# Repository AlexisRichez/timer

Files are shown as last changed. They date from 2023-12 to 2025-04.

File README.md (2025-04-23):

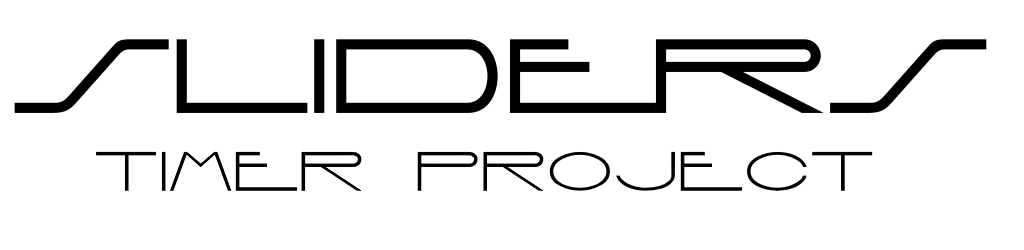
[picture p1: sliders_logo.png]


## Table of Contents
1. [Introduction](#introduction)
2. [Schematics](#schematics)
3. [PCB](#pcb)
4. [Power Supply](#power-supply)
5. [Hardware](#hardware)
6. [Sources](#sources)
7. [Remaining tasks](#remaining-tasks)

## Introduction
### About the story...
Sliders is a 1995 sci-fi television series :tv: that follows Quinn Mallory, a young genius who invents a device called the "Timer" that allows him and a small group of friends—Wade, Rembrandt, and Professor Arturo—to travel between parallel universes. Each universe presents a different version of Earth with unique cultures, histories, and technologies. The group "slides" from one world to the next, searching for their way back home while facing various challenges along the way.

The "Timer" is a handheld device that controls the sliding process, dictating how long the group must stay in each universe before they can slide again. It opens a wormhole :cyclone: at set intervals, and if the group misses their window, they are stranded in the current universe. The Timer becomes central to the story, especially when it malfunctions or is damaged, leading to unpredictable slides or dangerous situations.

### This is Open Source !
<b>Source Code:</b> You can download and modify the entire source code to suit your requirements. Whether you want to fix a bug, add new features, or create your own version, the choice is yours!

<b>3D Models:</b> All 3D models I use are accessible and can be adjusted. If you want to tweak the designs or use them for your own projects, you are free to do so.

<b>Vector Files:</b> Any vector graphic files I provide can also be edited. This includes things like logos, UI components, and other design assets that you can adapt for personal use.

> [!IMPORTANT]
> Feel free to fork this project for your own needs, or contribute directly by making a pull request :blush: :heart:

## Schematics
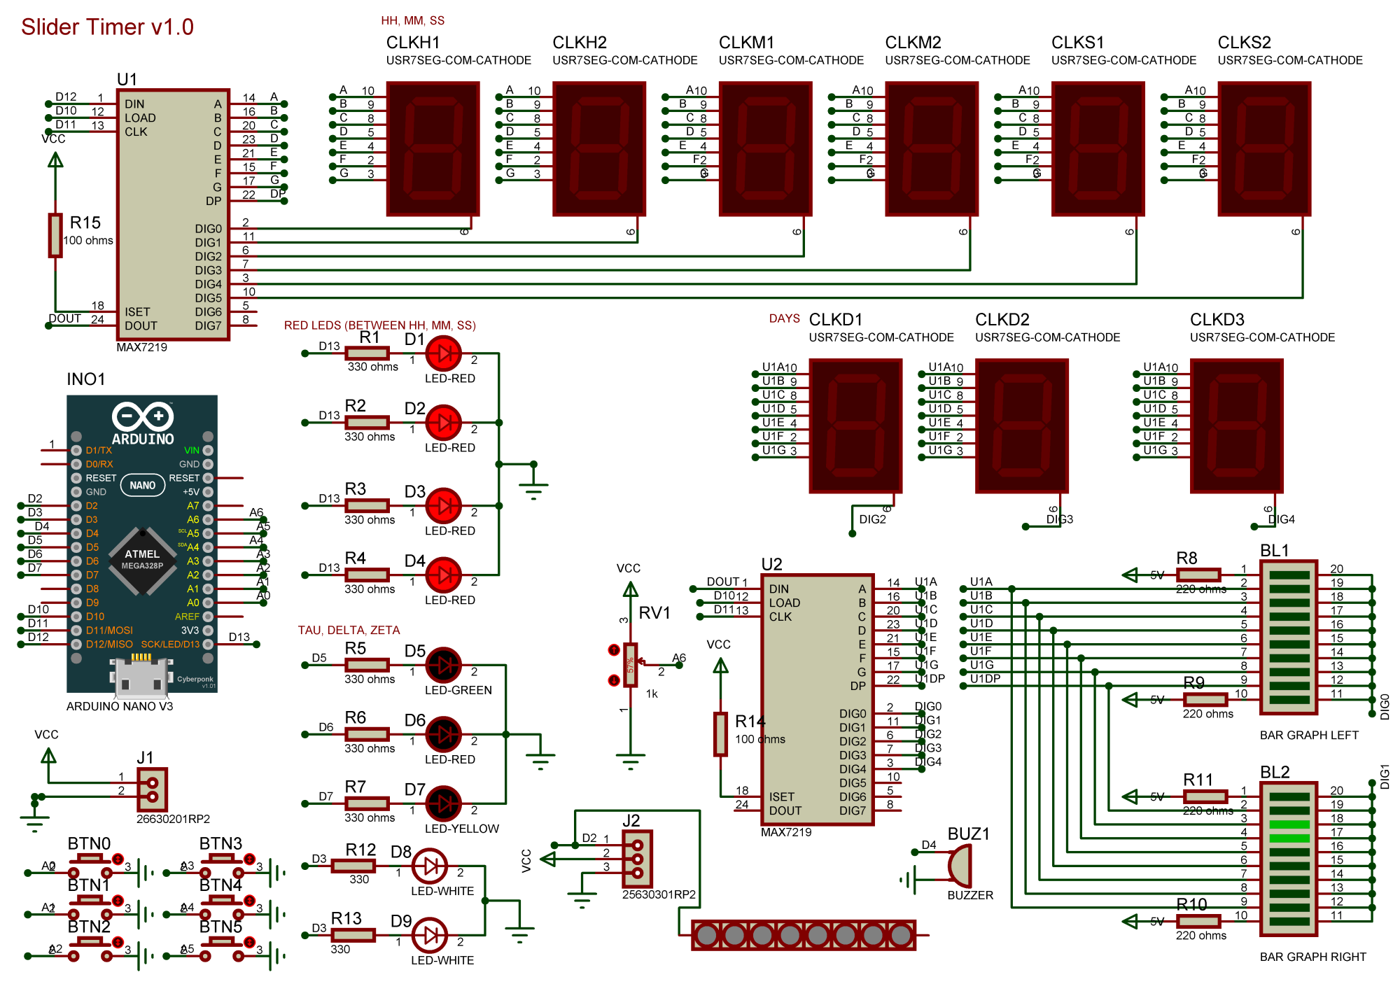
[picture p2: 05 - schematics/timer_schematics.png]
<br/>
## PCB
Size : 137mm x 50mm
## Power supply
### LiPo 3,7V 3000mAh 1S 1C
https://www.amazon.fr/dp/B08V11Z88Q
### Wemos D1 Battery Shield
The Wemos D1 Battery Shield is an expansion board designed for the Wemos D1 Mini series, allowing it to run on a lithium-ion (Li-Ion) or lithium-polymer (LiPo) battery. It features a TP4056 charging circuit for safe battery charging via micro-USB and includes a boost converter to provide a stable 5V output from the battery. Additionally, it has built-in overcharge and discharge protection to extend battery life and ensure safe operation. This shield is ideal for portable IoT projects, wireless sensor nodes, and other battery-powered applications.

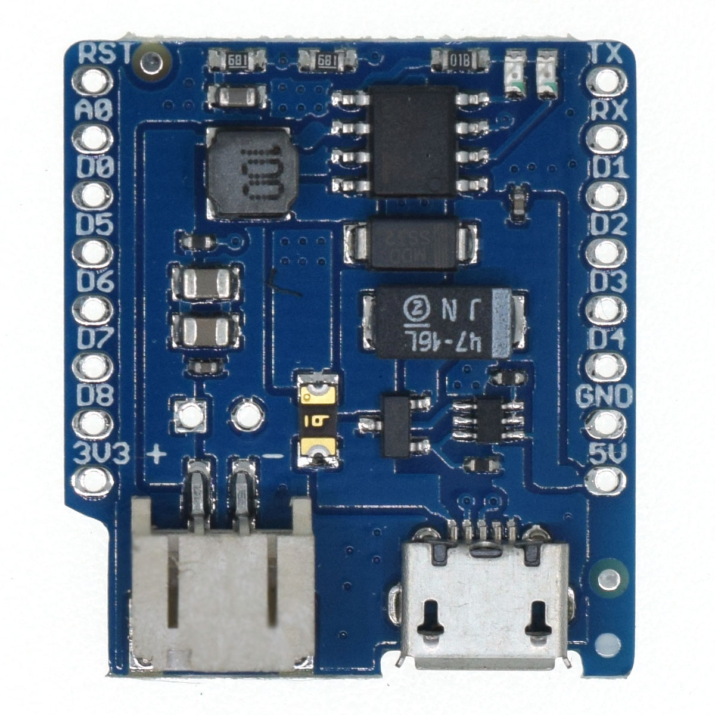
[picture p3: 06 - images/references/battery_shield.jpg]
<br/>

https://www.wemos.cc/en/latest/d1_mini_shield/battery.html
## Hardware
### Bill of materials
| Component | Link |
|---|---|
| 7 segment red LED digit - 0.36 inch cathode (HH:MM:SS) | https://fr.aliexpress.com/item/1005002680227414.html |
| 7 segment red LED digit - 0.3 inch cathode (DDD) | https://fr.aliexpress.com/item/32726538415.html |
| 10 green LEDs bargraph | https://fr.aliexpress.com/item/1005006697608767.html |
| Yellow, red, green LEDs (TAU, DELTA, ZETA) | https://fr.aliexpress.com/item/1005005678632501.html |
| Red LEDs (between HH:MM:SS) | https://fr.aliexpress.com/item/1005005678632501.html |
| Light LEDs (top laser) | https://fr.aliexpress.com/item/32468733055.html |
| Buzzer | https://fr.aliexpress.com/item/1005006209077202.html |
| Potentiometer 10k | https://fr.aliexpress.com/item/1005005671238738.html |
| Red acrylic sheets | [https://fr.aliexpress.com/item/4000283087852.html](https://fr.aliexpress.com/item/4000283087852.html) |
| Translucent acrylic sheets | [https://fr.aliexpress.com/item/4000283087852.html](https://fr.aliexpress.com/item/1005004925861639.html) |
| Arduino Nano V3 | [https://www.amazon.fr/dp/B0722YYBSS](https://www.amazon.fr/dp/B0722YYBSS) |

### Component Dimensions
> [!TIP]
> These are the dimensions used for the project. You should be able to use any component that adheres to these dimensions without needing to adapt anything on the PCB.

| Component | Length (mm) | Width (mm) | Height (mm) |
|---|---|---|---|
| 7 segment red LED digit - 0.36 inch cathode (HH:MM:SS) | 14.00 | 7.40 | 7.20 |
| 7 segment red LED digit - 0.3 inch cathode (DDD) | 12.70 | 7.60 | 7.00 |
| 10 green LEDs bargraph | 25.40 | 10.10 | 7.90 |
| Yellow, red, green LEDs (TAU, DELTA, ZETA) | 5.00 | 2.00 | 7.00 |
| Red LEDs (between HH:MM:SS) | 3.00 | 2.00 | 4.00 |
| Potentiometer 10k | - | - | - |

## Assembly & Finishing Tips
### Holes
The holes are designed for use with M2 or M3 inserts. Depending on the 3D printing technology used, the hole dimensions may need to be adjusted to ensure a precise fit:

- For filament prints :<br/>
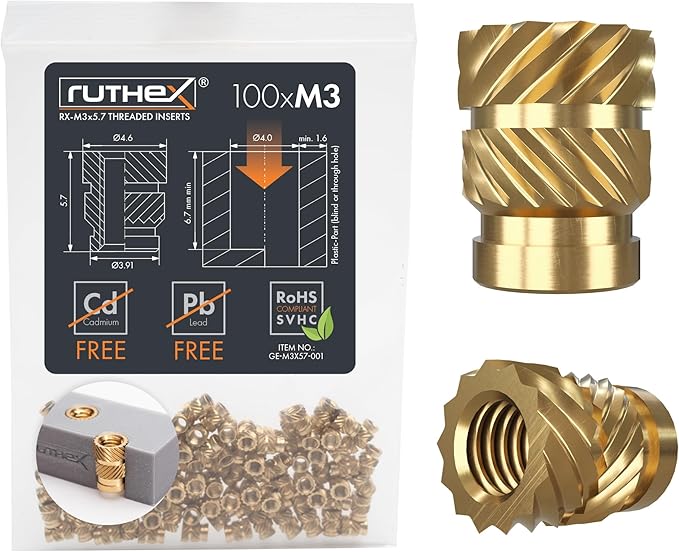
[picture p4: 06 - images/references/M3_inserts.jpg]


- For resin prints :<br/>
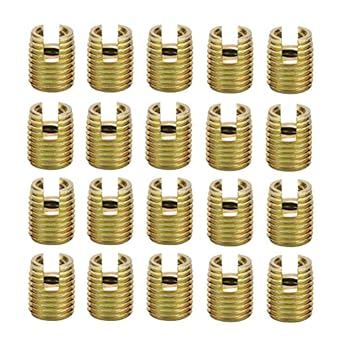
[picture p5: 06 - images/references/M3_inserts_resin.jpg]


### Buttons
For best results, print the buttons in white using a resin printer. After printing, spray them with black paint, then lightly sand the top surface — the text will become clearly visible. You can finish by applying a coat of varnish for protection and a polished look.

## 3D models
Timer 3D model preview : https://3dviewer.net/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<br/>
PCB 3D model preview : https://3dviewer.net/#model=https://raw.githubusercontent.com/AlexisRichez/timer/main/01%20-%20proteus/pcb.3DS

<div style="float:left">
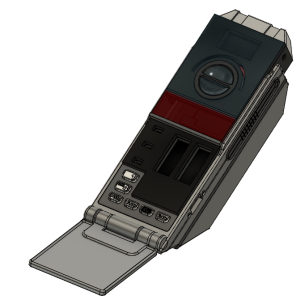
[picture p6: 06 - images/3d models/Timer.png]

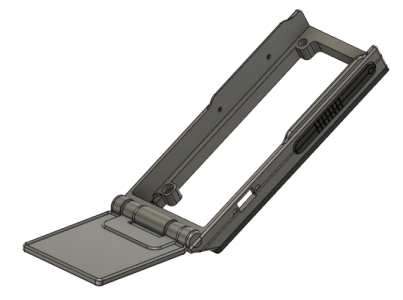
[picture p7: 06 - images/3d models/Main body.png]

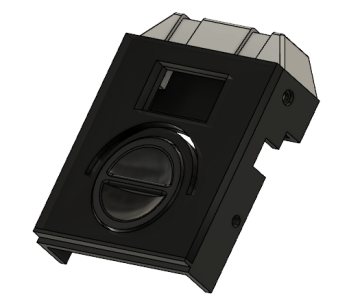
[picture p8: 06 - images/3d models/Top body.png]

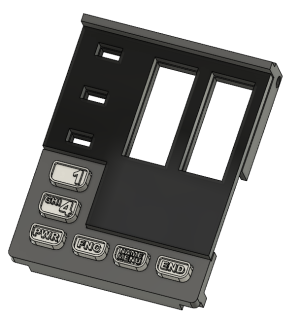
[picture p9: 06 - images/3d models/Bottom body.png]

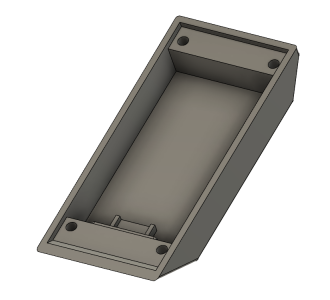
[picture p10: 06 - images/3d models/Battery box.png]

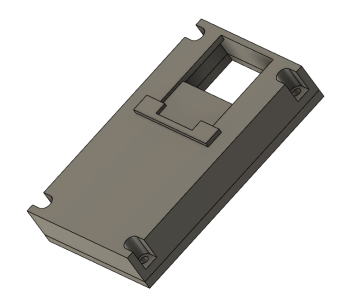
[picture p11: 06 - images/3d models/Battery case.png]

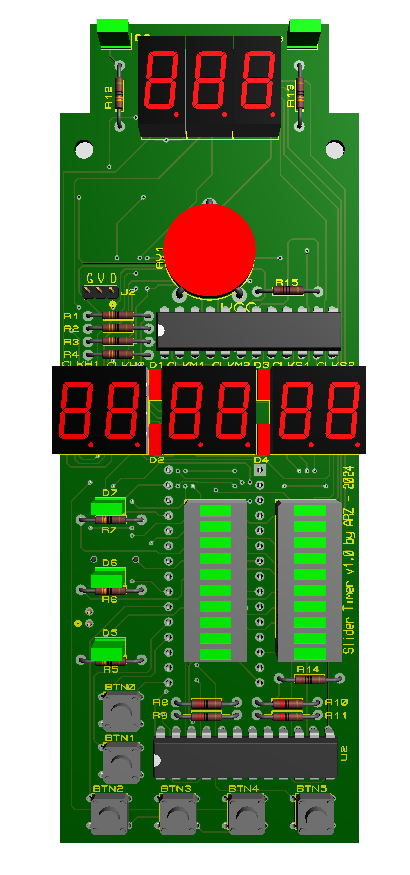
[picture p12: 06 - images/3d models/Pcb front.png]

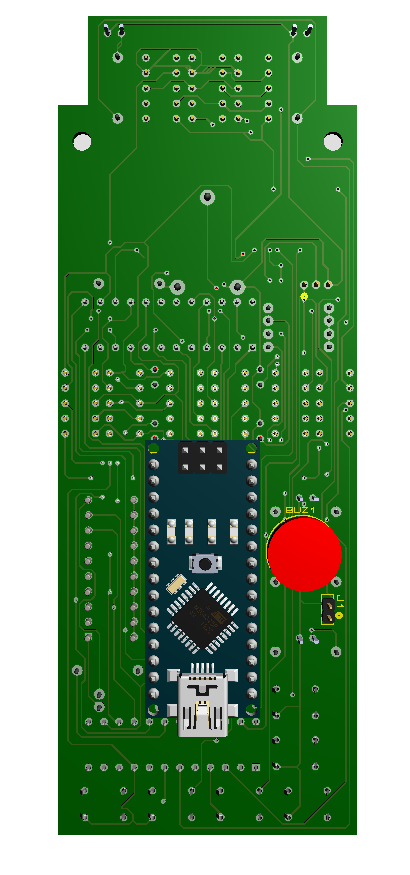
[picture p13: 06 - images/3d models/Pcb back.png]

</div>
<hr style="clear:both"/>

## Sources
+ [https://www.therpf.com/forums/threads/how-to-build-sliders-timer-electronics.104308/](https://www.therpf.com/forums/threads/how-to-build-sliders-timer-electronics.104308/)
+ https://github.com/kenny-caldieraro/Sliders-timer-replica

## Thingiverse
STL files are available on Thingiverse : https://www.thingiverse.com/thing:7009968

## Remaining tasks
:tada: Issues and improvments are available here : https://github.com/AlexisRichez/timer/issues<br/>

## Pictures :camera:
<div style="float:left">
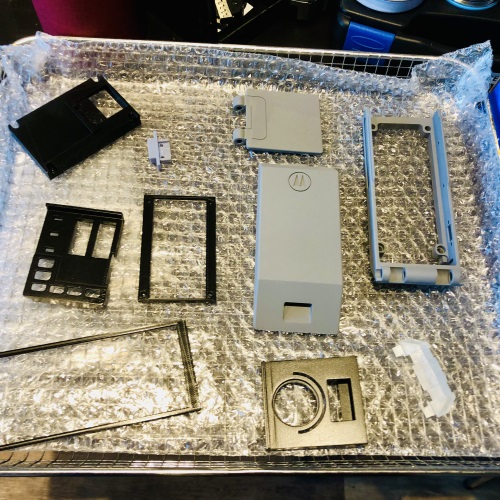
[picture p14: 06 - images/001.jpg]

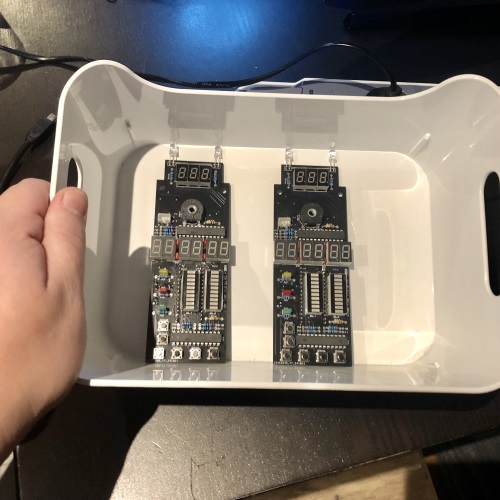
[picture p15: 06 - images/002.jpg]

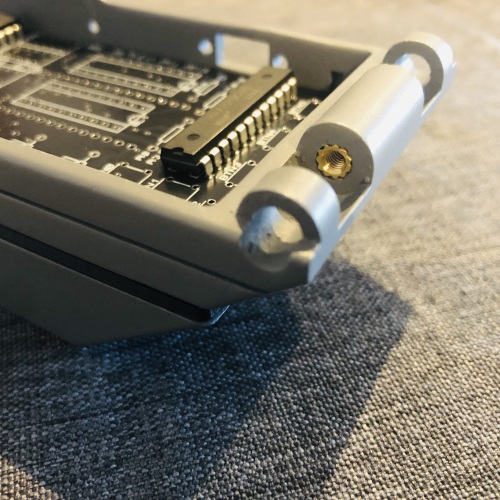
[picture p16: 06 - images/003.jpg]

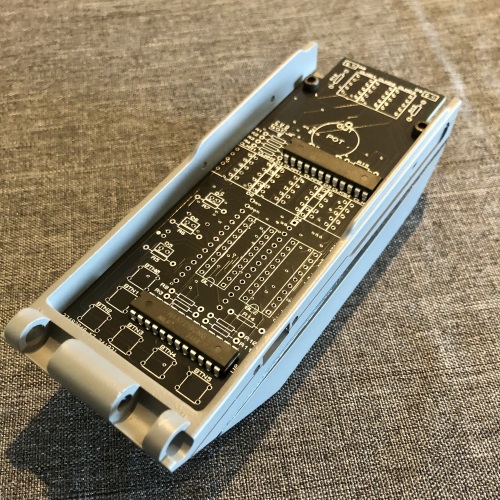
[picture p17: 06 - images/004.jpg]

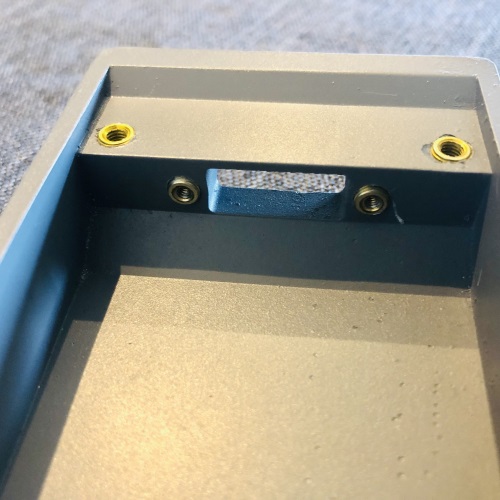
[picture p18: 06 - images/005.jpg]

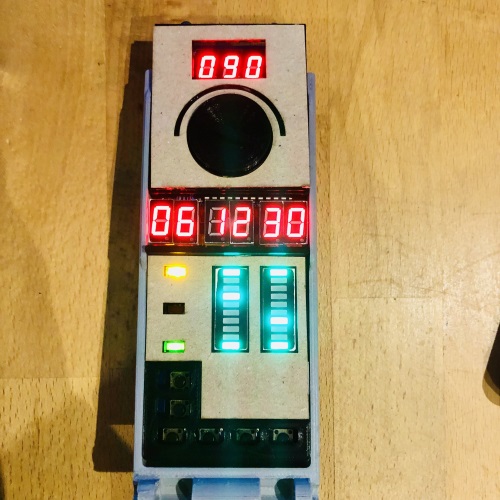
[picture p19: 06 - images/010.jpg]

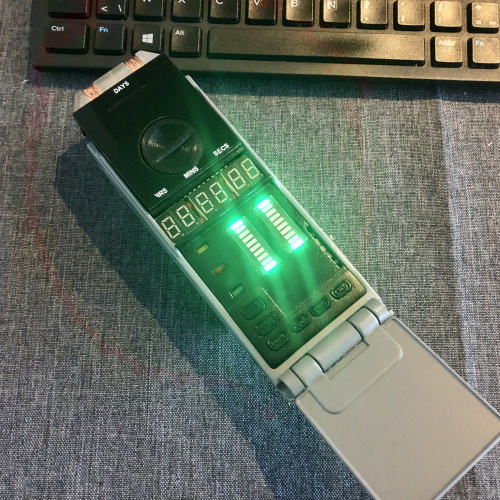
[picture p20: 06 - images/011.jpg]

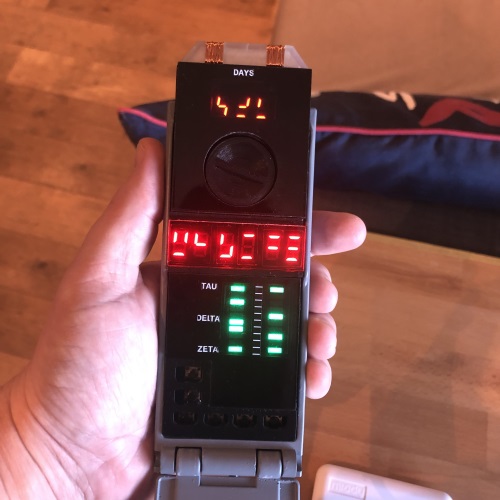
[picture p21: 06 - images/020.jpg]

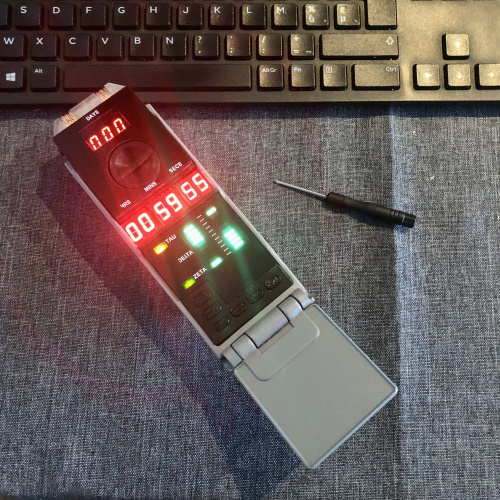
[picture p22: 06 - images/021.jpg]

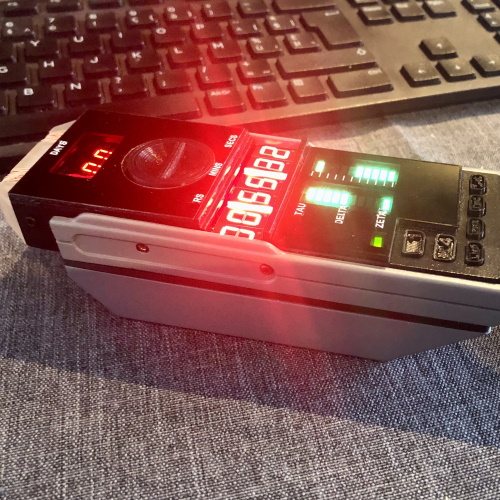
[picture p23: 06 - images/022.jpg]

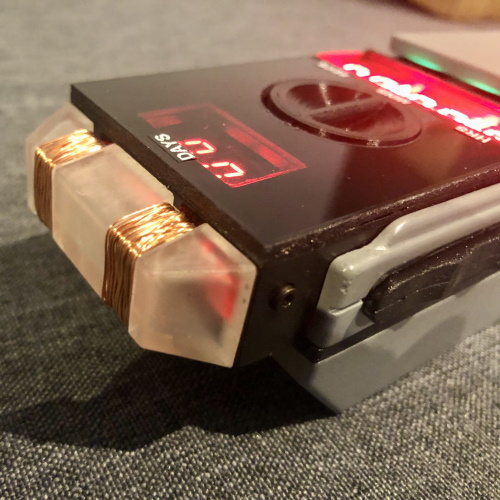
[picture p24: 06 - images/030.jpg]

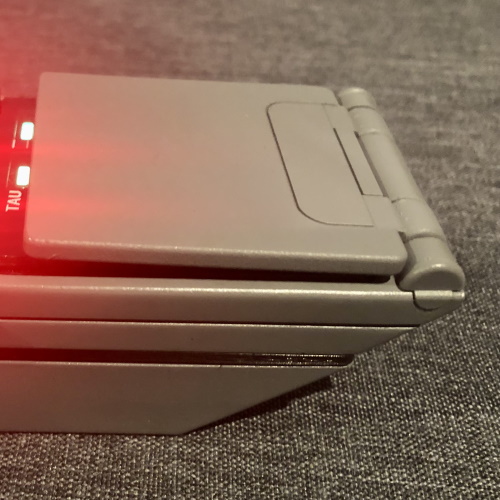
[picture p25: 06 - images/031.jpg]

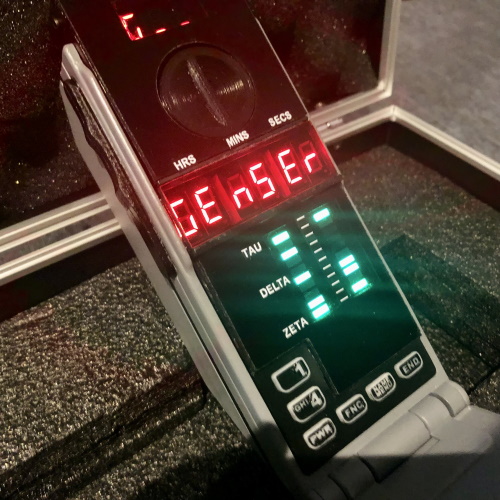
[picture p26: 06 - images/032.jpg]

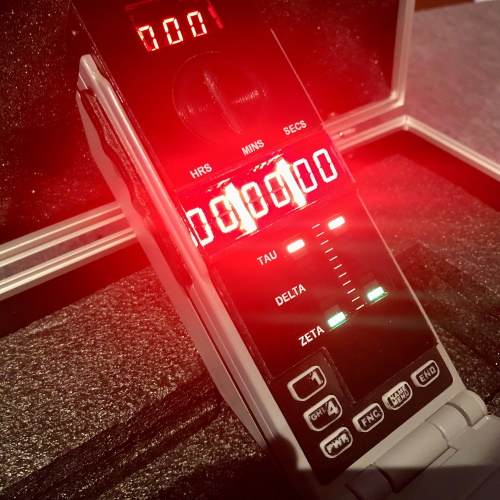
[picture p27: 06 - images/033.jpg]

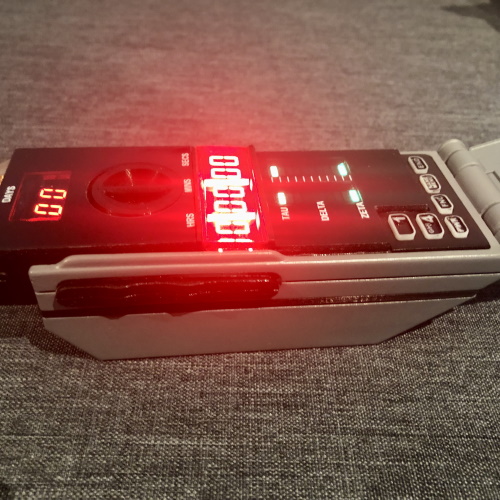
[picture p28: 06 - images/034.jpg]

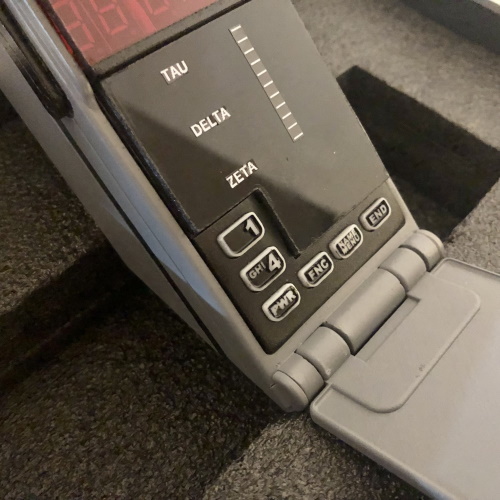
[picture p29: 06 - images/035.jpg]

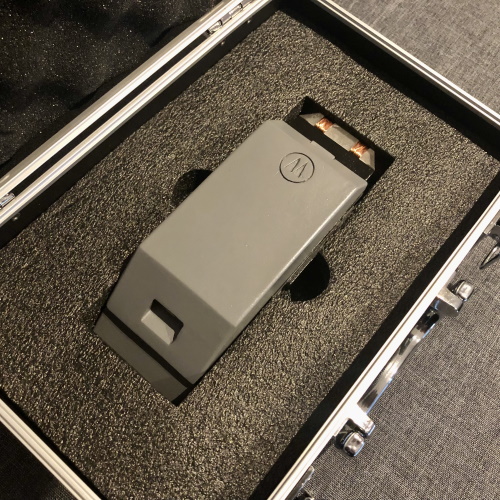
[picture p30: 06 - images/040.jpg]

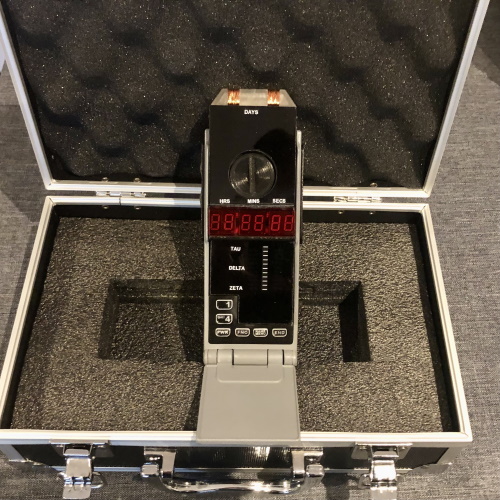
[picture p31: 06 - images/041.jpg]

</div>

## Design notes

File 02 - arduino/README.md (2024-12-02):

> [!TIP]
> You can download and modify the entire source code to suit your requirements. Whether you want to fix a bug, add new features, or create your own version, the choice is yours!

| Directory | Description |
| --- | --- |
| 01_test_components  | Can be used to simply test your PCB without any extra features  |
| 02_timer  | Timer source code :smirk:  |

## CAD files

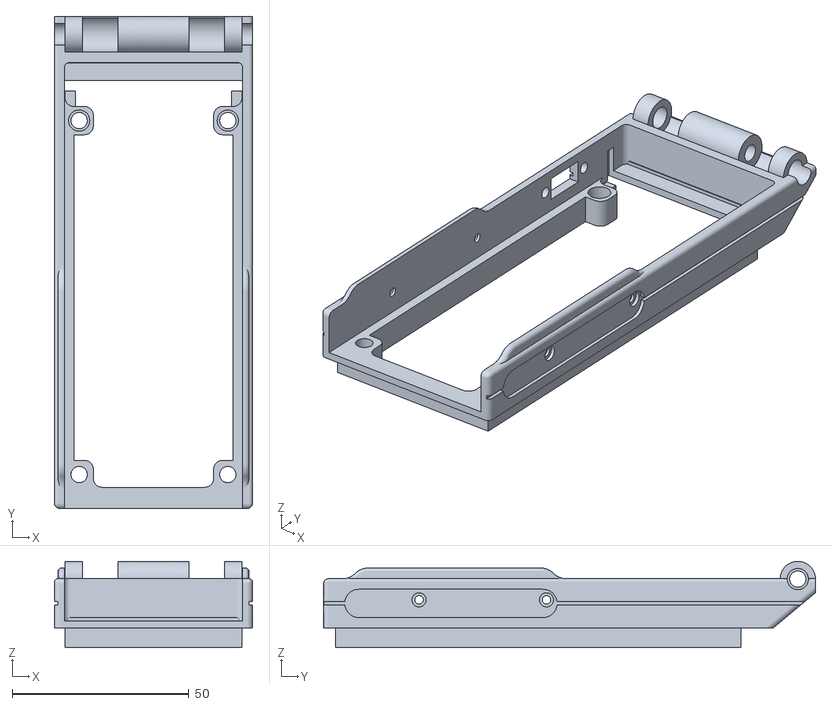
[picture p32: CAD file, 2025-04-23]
04 - stl/Main body.stl
56.0 x 139.0 x 24.4

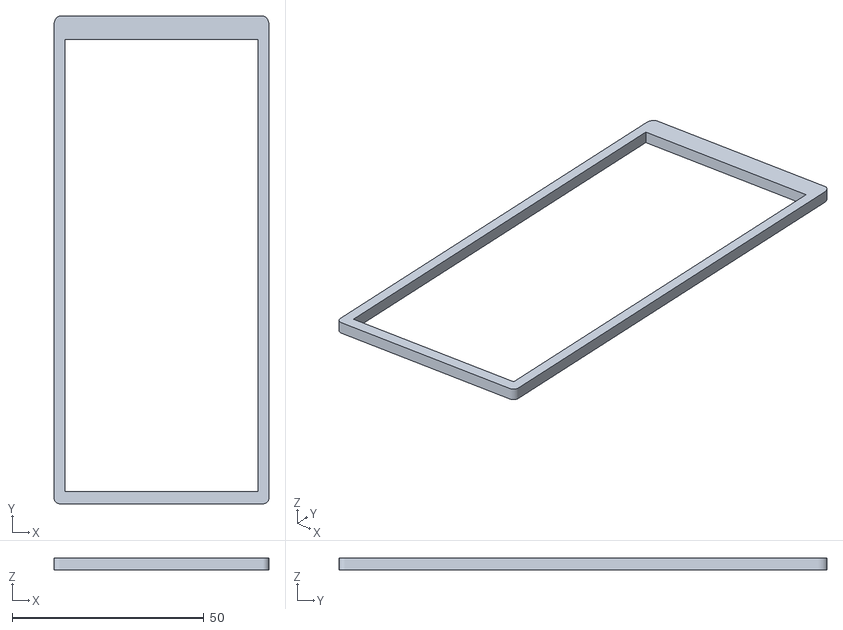
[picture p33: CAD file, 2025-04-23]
04 - stl/Main Body Frame.stl
56.0 x 127.0 x 3.00

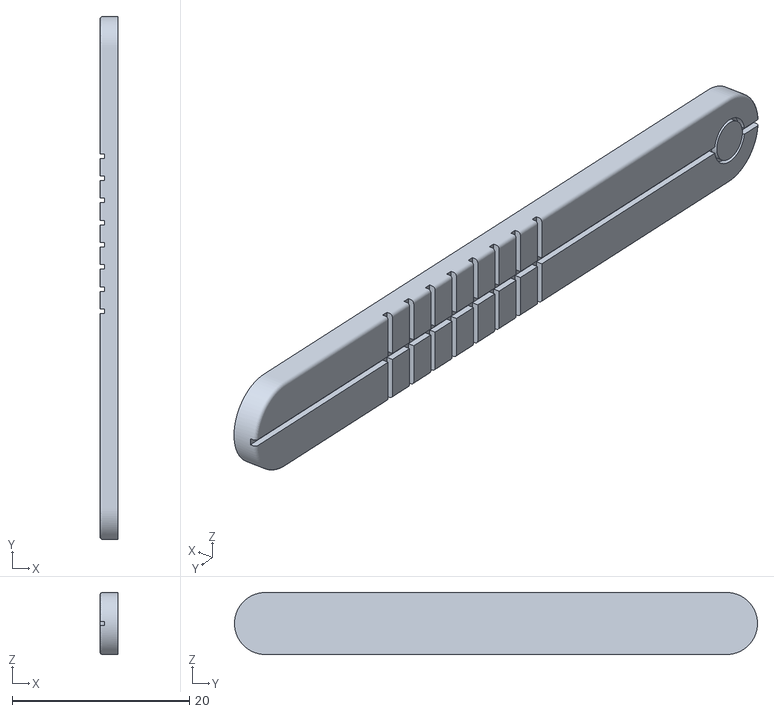
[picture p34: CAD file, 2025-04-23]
04 - stl/Main Body Right Side Panel.stl
2.00 x 59.0 x 7.00

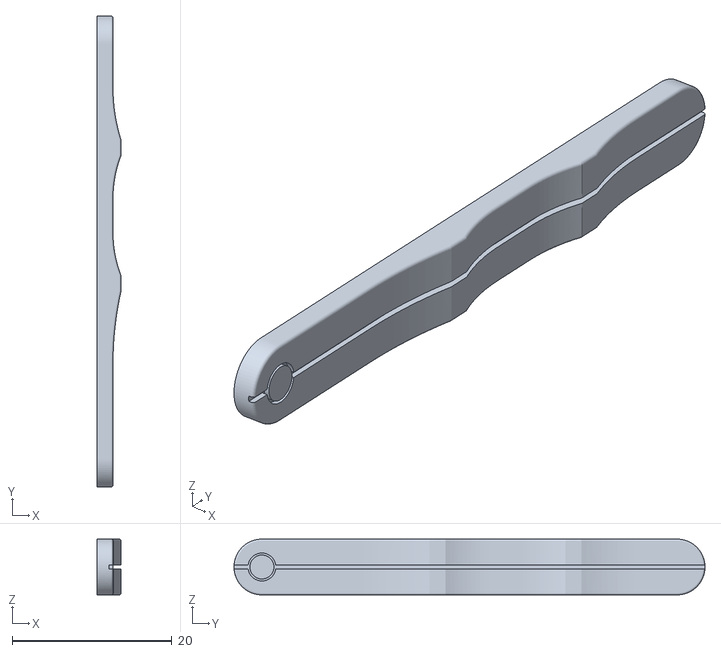
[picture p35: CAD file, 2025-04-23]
04 - stl/Main Body Left Side Panel.stl
3.00 x 59.0 x 7.00

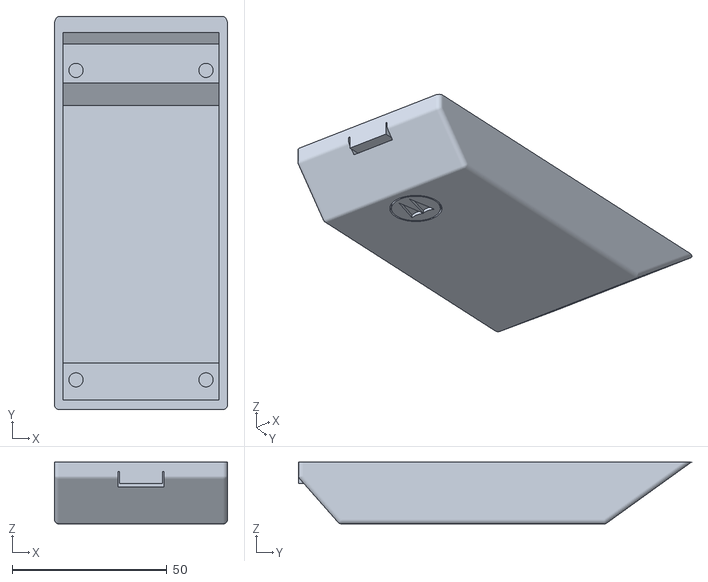
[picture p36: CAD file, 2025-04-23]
04 - stl/Battery Box.stl
56.0 x 127.0 x 20.0

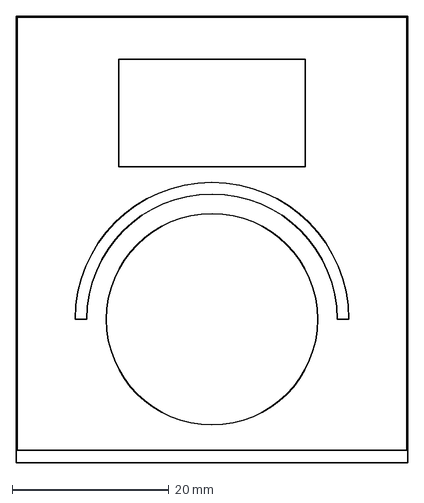
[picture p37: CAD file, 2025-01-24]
07 - laser cut/Laser cut - Top overlay.dxf
50.0 x 57.0 mm

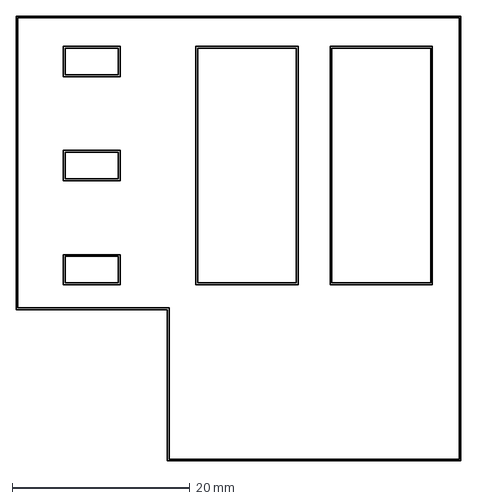
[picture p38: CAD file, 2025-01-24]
07 - laser cut/Laser cut - Bottom overlay.dxf
50.0 x 50.0 mm

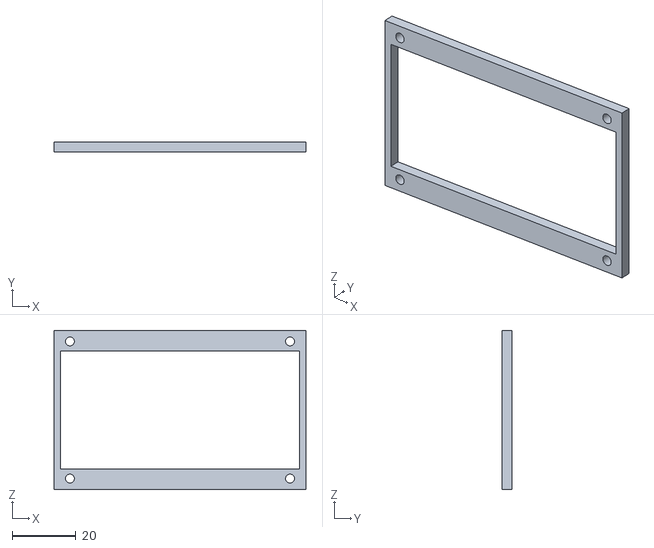
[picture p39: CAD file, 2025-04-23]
04 - stl/Battery Box Insert Support.stl
79.0 x 3.00 x 50.0

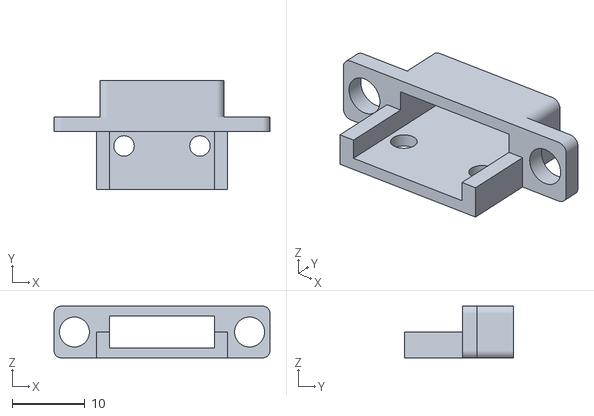
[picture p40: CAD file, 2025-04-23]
04 - stl/Battery Box Usb Adapter.stl
29.6 x 15.0 x 7.10

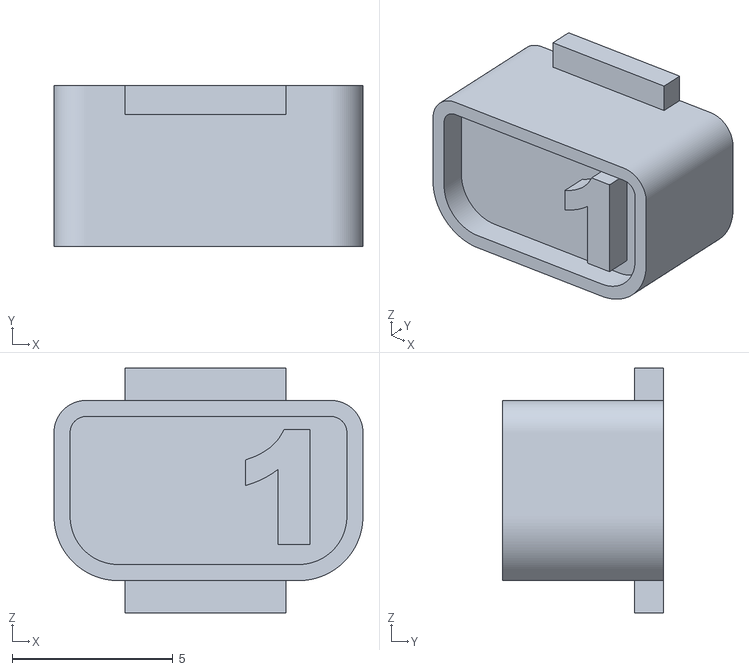
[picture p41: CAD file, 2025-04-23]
04 - stl/Button 1.stl
9.60 x 5.00 x 7.60

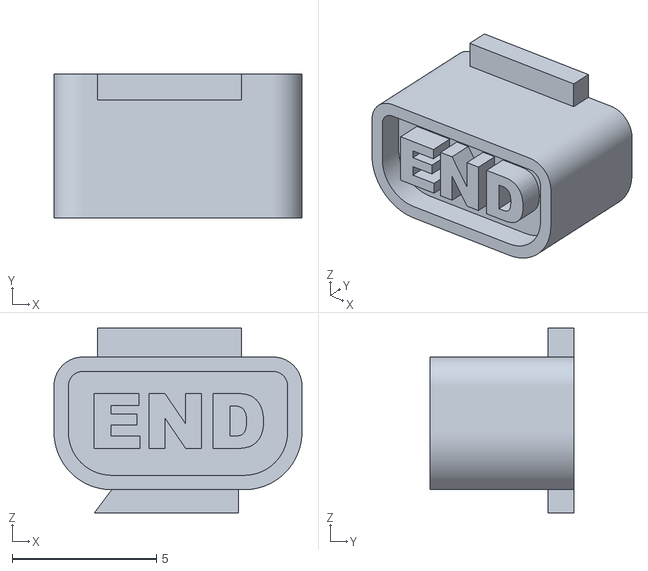
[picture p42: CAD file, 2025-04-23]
04 - stl/Button END.stl
8.60 x 5.00 x 6.40

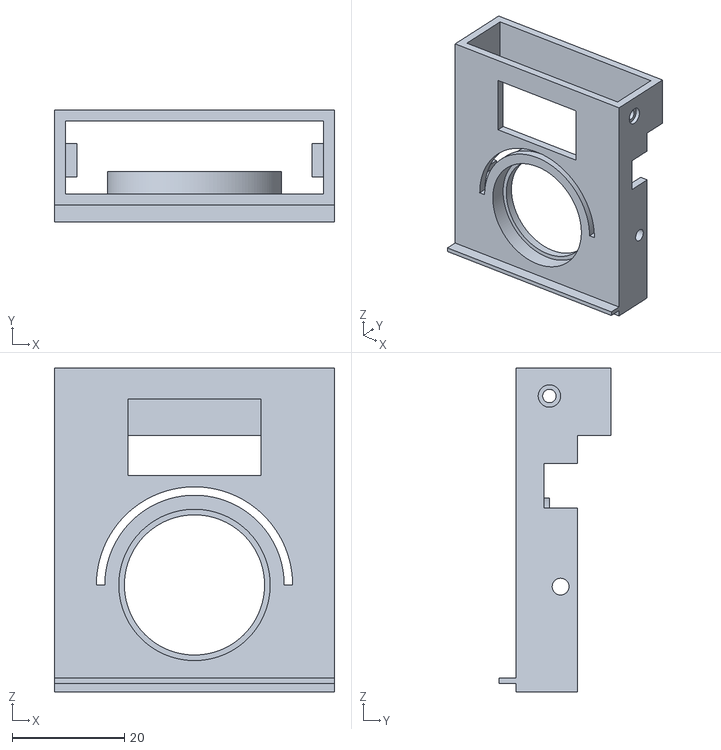
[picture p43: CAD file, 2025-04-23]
04 - stl/Top Plate.stl
50.0 x 20.0 x 57.8

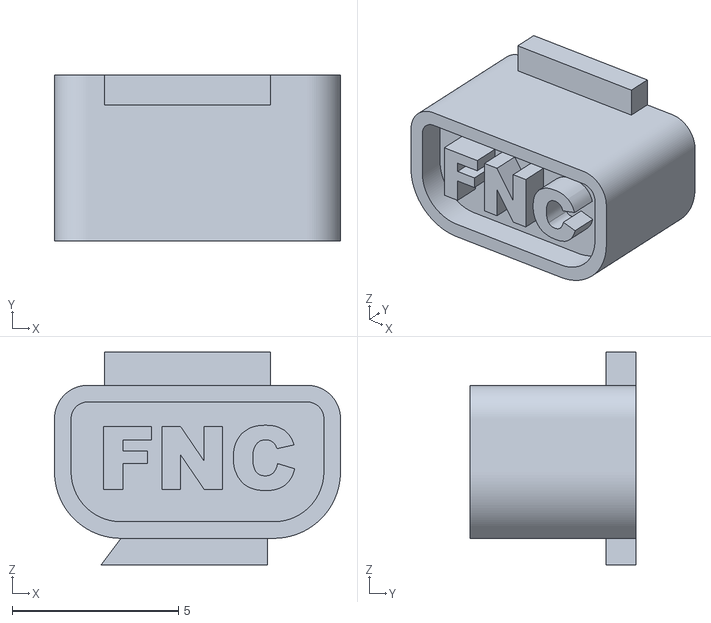
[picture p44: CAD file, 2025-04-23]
04 - stl/Button FCN.stl
8.60 x 5.00 x 6.40

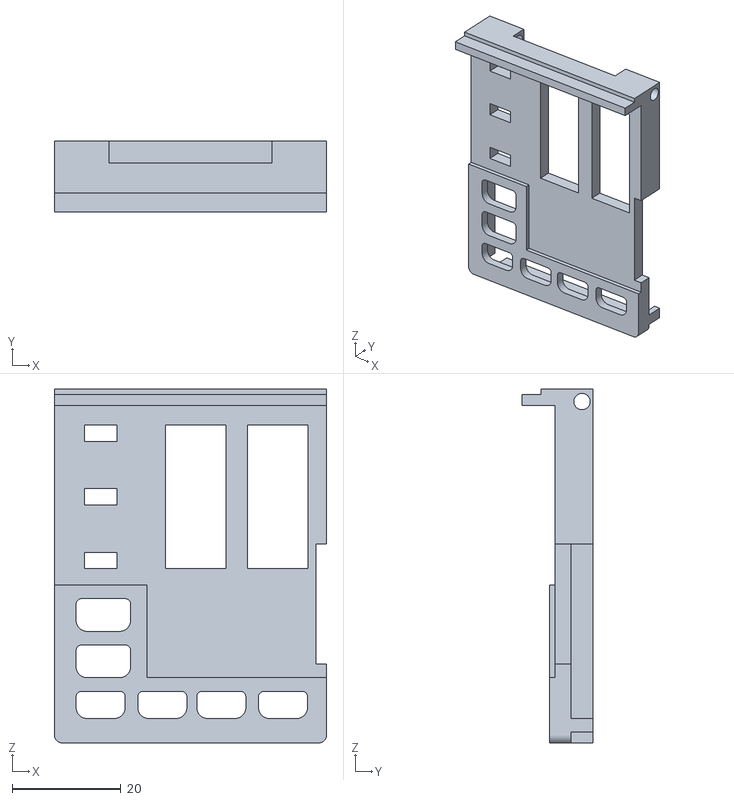
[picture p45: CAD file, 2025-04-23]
04 - stl/Bottom Plate.stl
50.0 x 13.0 x 65.0

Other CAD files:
04 - stl/Bottom Plate Flip Cover.stl
04 - stl/Bouton PWR.stl
04 - stl/Button NAME.stl
04 - stl/Top Plate Rounded button.stl
03 - fusion360/v2 - Timer - Assembly.f3z
03 - fusion360/v2 - Timer - Battery box.f3d
03 - fusion360/v2 - Timer - Bottom overlay.f3d
03 - fusion360/v2 - Timer - Led ring insert.f3d
03 - fusion360/v2 - Timer - Main body.f3d
03 - fusion360/v2 - Timer - PCB.f3d
03 - fusion360/v2 - Timer - Top overlay.f3d
04 - stl/Battery Box Insert.stl
04 - stl/Button 4.stl
04 - stl/Side Screw Hide Left.stl
04 - stl/Side Screw Hide Right.stl
04 - stl/Top Plate Laser.stl

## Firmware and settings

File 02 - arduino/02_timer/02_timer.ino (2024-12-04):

#include "LedControl.h"
#include "OneButton.h"
#include "Adafruit_NeoPixel.h"

//Source for specs : https://www.therpf.com/forums/threads/how-to-build-sliders-timer-electronics.104308/

// MAX7219 configuration
#define PIN_MAX72_DATA_IN 12
#define PIN_MAX72_CLK 11
#define PIN_MAX72_LOAD 10
#define MAX72_NB_DEVICES 2
LedControl lc = LedControl(PIN_MAX72_DATA_IN, PIN_MAX72_CLK, PIN_MAX72_LOAD, MAX72_NB_DEVICES);

// Global led configuration
#define DEFAULT_INTENSITY_LED 10

//Slide lights (white leds on top)
#define PIN_WHITE_COLONS_LED 3

// Power led ring
#define LEDRING_PIN 2
#define LEDRING_NUMPIXELS 8
Adafruit_NeoPixel pixels(LEDRING_NUMPIXELS, LEDRING_PIN, NEO_GRB + NEO_KHZ800);
int Pot;

//Buzzer
#define PIN_BUZZER 4

//Red led columns (Between HH, MM, SS)
#define PIN_RED_COLONS_LED 13
long blinkRedColumnsIntervalDefault = 500;
long blinkRedColumnsInterval = blinkRedColumnsIntervalDefault;
long previousBlinkRedColumnsMillis = 0;
bool redColumnsStatus = false;

// TAU, DELTA, ZETA
#define PIN_YELLOW_LED 7
#define PIN_RED_LED 6
#define PIN_GREEN_LED 5
bool tauStatus = false;
bool deltaStatus = false;
bool zetaStatus = false;
unsigned long previousBlinkTauMillis = 0;
unsigned long previousBlinkDeltaMillis = 0;
unsigned long previousBlinkZetaMillis = 0;

//Buttons
const unsigned long debounceDelay = 50; // Debounce delay in milliseconds
unsigned long lastDebounceTimes[6] = {0}; // Last debounce times for each button
static bool lastButtonStates[6] = {HIGH, HIGH, HIGH, HIGH, HIGH, HIGH}; // Track previous button states
static bool actionButtonExecuted[6] = {false}; // Track whether the action has been executed

#define BTN_1 A0
#define BTN_2 A1
#define BTN_3 A2
#define BTN_4 A3
#define BTN_5 A4
#define BTN_6 A5

//Edit mode
long previousBlinkEditModeMillis = 0;
long previousBlinkEditModeInterval = 250;
bool editModeBlinkStatus = false;

//Bargraph
byte bargraph_patterns[] = {
  B00000000,
  B10000000,
  B10000001,
  B10000011,
  B10000111,
  B10001111,
  B10011111,
  B10111111,
  B11111111,
  B10111111,
  B10011111,B10001111,B10000111,B10000011,B10000001,B10000000
  };
#define BARGRAPH_INTERVAL 100 // Bar graph interval in milliseconds
#define BARGRAPH_NUM_PATTERNS (sizeof(bargraph_patterns) / sizeof(bargraph_patterns[0]))
byte bargraphPatternIndex = 0; // Index to track which pattern to show
unsigned long previousBarGraphMillis = 0;

//Timer management
unsigned long previousTimerMillis = 0;
unsigned long totalsectime = 0;
bool firstLoop = true;
bool nextLoop = false;
bool randomMode = false;
bool editMode = true;
long editModeCurrent = 0;
long editModeSeconds = 0;
long editModeMinutes = 0;
long editModeHours = 0;
long editModeDays = 0;
bool powerOn = false;
bool isTimerOn = false;
bool countdownEndTriggered = false;
bool isTimerSleepMode = false;

//Options
const bool buzzerActivated = true;

void setup()
{
  Serial.println("Sliders Timer System by ARZ");
  Serial.println("===========================================");
  Serial.println("Made with love in FRANCE");
  
  Serial.begin(115200);

  randomSeed(analogRead(0)); // Seed the random number generator with an analog reading
  
  //Two MAX7219 initialisation
  int devices = lc.getDeviceCount();
  for (int address = 0; address < devices; address++)
  {
    lc.shutdown(address, false);
    lc.clearDisplay(address);
    lc.setIntensity(address, DEFAULT_INTENSITY_LED);
    lc.setScanLimit(address, 8);
  }

  //Buzzer
  pinMode(PIN_BUZZER, OUTPUT);
  //Red led two columns
  pinMode(PIN_RED_COLONS_LED, OUTPUT);
  //Slide lights on top
  pinMode(PIN_WHITE_COLONS_LED, OUTPUT);

  //TAU, DELTA, ZETA
  pinMode(PIN_GREEN_LED, OUTPUT);
  pinMode(PIN_RED_LED, OUTPUT);
  pinMode(PIN_YELLOW_LED, OUTPUT);

  //Buttons
  pinMode(BTN_1, INPUT_PULLUP);
  pinMode(BTN_2, INPUT_PULLUP);
  pinMode(BTN_3, INPUT_PULLUP);
  pinMode(BTN_4, INPUT_PULLUP);
  pinMode(BTN_5, INPUT_PULLUP);
  pinMode(BTN_6, INPUT_PULLUP);

  //Calculate next random countdown only if we are in random mode
  if(randomMode)
  {
    setNextRandCountdown();
  }
}

//Deactivate slide mode : reset everything specific to slide mode (X min before countdown end)
void deactivateSlideMode()
{
  deactivateSlideLights();
}

//Activate slide mode
void activateSlideMode()
{
  activateSlideLights();
}

//Define next random countdown
void setNextRandCountdown()
{
  Serial.println("Set next random countdown...");
  //totalsectime = random(16756131);
  totalsectime = random(600, 604800); //Random between 10 minutes and 7 days
  Serial.println("Total time in seconds : " + totalsectime);
  countdownEndTriggered = false;
}

//Deactivate slide lights
void deactivateSlideLights()
{
    digitalWrite(PIN_WHITE_COLONS_LED, LOW);
}

//Acticate slide lights
void activateSlideLights()
{
    digitalWrite(PIN_WHITE_COLONS_LED, HIGH);
}

//Activate red led columns
void activateRedColumnsLeds()
{
  digitalWrite(PIN_RED_COLONS_LED, HIGH);
}

//Blink  red leds columns
void blinkRedColumnsLeds()
{
  unsigned long currentMillis = millis();
  if (currentMillis - previousBlinkRedColumnsMillis >= blinkRedColumnsInterval)
  {
    previousBlinkRedColumnsMillis = currentMillis;
    blinkRedColumnsInterval = blinkRedColumnsIntervalDefault;
    
    //When 30 seconds or less are remaining, red leds and buzzer speeds up
    if(totalsectime<=30)
    {
      blinkRedColumnsInterval = 150;
    }

    // Toggle the LED status
    redColumnsStatus = !redColumnsStatus;
    
    //Blink red colons
    if(redColumnsStatus && buzzerActivated && totalsectime<=60)
    {
      tone(PIN_BUZZER, 5500, 100);
    }
    
    // Update the LED output based on the status
    digitalWrite(PIN_RED_COLONS_LED, redColumnsStatus ? HIGH : LOW);
  }
}

//Blink TAU
void blinkTAU()
{
  unsigned long currentMillis = millis();
  if (currentMillis - previousBlinkTauMillis >= 250)
  {
    previousBlinkTauMillis = currentMillis;
    if((totalsectime >= 15 && totalsectime <= 35)) {
      digitalWrite(PIN_YELLOW_LED, HIGH);
    } else {
      tauStatus = !tauStatus;
      digitalWrite(PIN_YELLOW_LED, tauStatus ? HIGH : LOW);
    }
  }
}

//Blink DELTA
void blinkDELTA()
{
  unsigned long currentMillis = millis();
  if (currentMillis - previousBlinkDeltaMillis >= 600)
  {
    previousBlinkDeltaMillis = currentMillis;
    if((totalsectime >= 0 && totalsectime <= 15)) {
      digitalWrite(PIN_RED_LED, HIGH);
    } else {
      deltaStatus = !deltaStatus;
      digitalWrite(PIN_RED_LED, deltaStatus ? HIGH : LOW);
    }
  }  
}

//Blink ZETA
void blinkZETA()
{
  unsigned long currentMillis = millis();
  if (currentMillis - previousBlinkZetaMillis >= 200)
  {
    previousBlinkZetaMillis = currentMillis;
    if((totalsectime >= 35 && totalsectime <= 59)) {
      digitalWrite(PIN_GREEN_LED, HIGH);
    } else {  
      zetaStatus = !zetaStatus;
      digitalWrite(PIN_GREEN_LED, zetaStatus ? HIGH : LOW);
    }
  }
}

//Blink TAU, DELTA, ZETA leds
void blinkTDZ()
{
  if(isTimerSleepMode)
  {
    digitalWrite(PIN_YELLOW_LED, LOW);
    digitalWrite(PIN_RED_LED, LOW);
    digitalWrite(PIN_GREEN_LED, LOW);
    return;
  }
  blinkTAU();
  blinkDELTA();
  blinkZETA();
}

//Blink modification when in edit mode
void blinkEditMode()
{
  unsigned long currentMillis = millis();
  if (currentMillis - previousBlinkEditModeMillis >= previousBlinkEditModeInterval)
  {
    previousBlinkEditModeMillis = currentMillis;

    if(isTimerSleepMode)
    {
      return;
    }
    
    if (editMode) {
      if (editModeCurrent == 4)
      {
        int days = totalsectime / 86400;
        if (editModeBlinkStatus)
        {
          lc.setRow(1, 2, B00000000); // Turn off the display
          lc.setRow(1, 3, B00000000); // Turn off the display
          lc.setRow(1, 4, B00000000); // Turn off the display
        }
        else
        {
          lc.setDigit(1, 2, days / 100, false);
          lc.setDigit(1, 3, (days / 10) % 10, false);
          lc.setDigit(1, 4, days % 10, false); 
        }
      }
      if (editModeCurrent == 3)
      {
        int hours = (totalsectime % 86400) / 3600;
        if (editModeBlinkStatus)
        {
          lc.setRow(0, 0, B00000000);
          lc.setRow(0, 1, B00000000);
        }
        else
        {
          lc.setDigit(0, 0, hours / 10, false);
          lc.setDigit(0, 1, hours % 10, false);   
        }
      }
      if (editModeCurrent == 2)
      {
        int minutes = (totalsectime % 3600) / 60;
        if (editModeBlinkStatus)
        {
          lc.setRow(0, 2, B00000000);
          lc.setRow(0, 3, B00000000);
        }
        else
        {
          lc.setDigit(0, 2, minutes / 10, false);
          lc.setDigit(0, 3, minutes % 10, false);    
        }
      }
      if (editModeCurrent == 1)
      {
        int seconds = totalsectime % 60;
        if (editModeBlinkStatus)
        {
          lc.setRow(0, 4, B00000000);
          lc.setRow(0, 5, B00000000);
        }
        else
        {
          lc.setDigit(0, 4, seconds / 10, false);
          lc.setDigit(0, 5, seconds % 10, false);     
        }
      }
      // Toggle the blinking status
      editModeBlinkStatus = !editModeBlinkStatus;
    }
  }
}

//Refresh timer
void refreshTimer()
{
    //Serial.println("Refresh timer...");
    int days = totalsectime / 86400;
    int hours = (totalsectime % 86400) / 3600;// Calculate hours from the remaining seconds after days
    int minutes = (totalsectime % 3600) / 60; // Calculate minutes from the remaining seconds after hours
    int seconds = totalsectime % 60; // Calculate seconds from the remaining seconds

    if(isTimerSleepMode)
    {
      lc.setRow(1, 2, B00000000);
      lc.setRow(1, 3, B00000000);
      lc.setRow(1, 4, B00000000);
      lc.setRow(0, 0, B00000000);
      lc.setRow(0, 1, B00000000);          
      lc.setRow(0, 2, B00000000);
      lc.setRow(0, 3, B00000000);
      lc.setRow(0, 4, B00000000);
      lc.setRow(0, 5, B00000000);
      return;
    }
  
    days = min(days, 999);
  
    // Update DDD display
    if(editMode && editModeCurrent == 4)
    {
      Serial.println("Days are edited");
    } else {
      lc.setDigit(1, 2, days / 100, false);
      lc.setDigit(1, 3, (days / 10) % 10, false);
      lc.setDigit(1, 4, days % 10, false);   
    }
    // Update the HHMMSS display
    if(editMode && editModeCurrent == 3)
    {
      Serial.println("Hours are edited");
    } else {
     lc.setDigit(0, 0, hours / 10, false); // Display tens digit of hours
     lc.setDigit(0, 1, hours % 10, false); // Display ones digit of hours     
    }
    if(editMode && editModeCurrent == 2)
    {
      Serial.println("Minutes are edited");
    } else {
      lc.setDigit(0, 2, minutes / 10, false); // Display tens digit of minutes
      lc.setDigit(0, 3, minutes % 10, false); // Display ones digit of minutes      
    }
    if(editMode && editModeCurrent == 1)
    {
      Serial.println("Seconds are edited");
    } else {
      lc.setDigit(0, 4, seconds / 10, false); // Display tens digit of seconds
      lc.setDigit(0, 5, seconds % 10, false); // Display ones digit of seconds    
    }
}

//Timer management
void timer(bool editMode = false)
{
  unsigned long currentMillis = millis();
  // Update the timer every second
  if (currentMillis - previousTimerMillis >= 1000)
  {
    previousTimerMillis = currentMillis;
    if(!editMode)
    {
      if (totalsectime > 0) {
        totalsectime--; // Decrease the timer value by 1 second if it's greater than 0
        isTimerOn = true;
      }
      else {
        isTimerOn = false;
      }  
    }
  }

  refreshTimer();

  if(editMode)
  {
    return;
  }
  
  if(totalsectime <= 0)
  {
    if(!countdownEndTriggered)
    {
      slideOpenVortex();
      genserOne();
      displayWrap();      
      countdownEndTriggered = true;
    }
    //Calculate next random countdown only if we are in random mode
    if(randomMode)
    {
      setNextRandCountdown();
    }
  }
}

//Bargraph management
void bargraph()
{
  unsigned long currentMillis = millis();

  if (currentMillis - previousBarGraphMillis >= BARGRAPH_INTERVAL)
  {
    previousBarGraphMillis = currentMillis;

    // Display the current pattern from the array
    byte pattern = bargraph_patterns[bargraphPatternIndex];
    if(isTimerSleepMode)
    {
      lc.setRow(1, 0, B00000000);
      lc.setRow(1, 1, B00000000);
    } else {
      lc.setRow(1, 0, pattern);
      lc.setRow(1, 1, pattern);
    }
    // Update the patternIndex to cycle through the patterns
    bargraphPatternIndex++;
    if (bargraphPatternIndex >= BARGRAPH_NUM_PATTERNS) {
      bargraphPatternIndex = 0; // Reset to the first pattern when the last one is reached
    }
  }
}

//Buzzer startup management
void buzzerStartup() {
  Serial.println("Buzzer startup sequence...");
  tone(PIN_BUZZER, 5500, 150);
  delay(200);
  tone(PIN_BUZZER, 5500, 150);
  delay(200);
  tone(PIN_BUZZER, 5500, 10);
  delay(10);
  tone(PIN_BUZZER, 5500, 10);
  delay(10);
  tone(PIN_BUZZER, 5500, 10);
  delay(10);
  tone(PIN_BUZZER, 5500, 10);
  delay(10);
  tone(PIN_BUZZER, 5500, 10);
  delay(10);
  tone(PIN_BUZZER, 5500, 10);
  delay(10);
  tone(PIN_BUZZER, 5500, 10);
  delay(10);
  tone(PIN_BUZZER, 5500, 10);
  delay(10);
  tone(PIN_BUZZER, 5500, 10);
  delay(10);
  tone(PIN_BUZZER, 5500, 10);
  delay(10);
  tone(PIN_BUZZER, 5500, 10);
  delay(10);
  tone(PIN_BUZZER, 5500, 10);
  delay(10);
  tone(PIN_BUZZER, 5500, 10);
  delay(10);
  tone(PIN_BUZZER, 5500, 10);
  delay(10);
  tone(PIN_BUZZER, 5500, 10);
  delay(10);
  tone(PIN_BUZZER, 3500, 100);
  delay(100);
  tone(PIN_BUZZER, 3500, 500);
  delay(250);
  tone(PIN_BUZZER, 2500, 500);
  delay(250);
  tone(PIN_BUZZER, 1500, 500);
  delay(250);
  noTone(PIN_BUZZER);
  delay(250);
}
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
void loop()
{
  //Blink when in edit mode
  blinkEditMode();
  
  //Buttons clicks
  clickButton(BTN_1,clickBtn1Action);
  clickButton(BTN_2,clickBtn4Action);
  clickButton(BTN_3,clickBtnPowerAction);
  clickButton(BTN_4,clickBtnFCNAction);
  clickButton(BTN_5,clickBtnNameAction);
  clickButton(BTN_6,clickBtnEndAction);  

  //Occurs only the first time : startup animations
  while (firstLoop) {
    if(buzzerActivated)
    {
      buzzerStartup();
    }
    genserOne();
    displayWrap();
    firstLoop = false;
    break;
  }

  //Occurs only when a countdown is defined (random or defined by a slider user)
  if(isTimerOn)
  {
    blinkRedColumnsLeds();
    bargraph();
    blinkTDZ();
  } else {
    activateRedColumnsLeds();
  }
   
  timer(editMode);
}

//Loop on HH MM SS
void loopHHMMSS() {
  Serial.println("Loop on HH:MM:SS...");
  lc.setRow(0, 0, B01000000);
  lc.setRow(0, 1, B00000000);
  lc.setRow(0, 2, B00000000);
  lc.setRow(0, 3, B00000000);
  lc.setRow(0, 4, B00000000);
  lc.setRow(0, 5, B00000000);
  delay(50);
  lc.setRow(0, 0, B01000000);
  lc.setRow(0, 1, B01000000);
  lc.setRow(0, 2, B00000000);
  lc.setRow(0, 3, B00000000);
  lc.setRow(0, 4, B00000000);
  lc.setRow(0, 5, B00000000);
  delay(50);
  lc.setRow(0, 0, B01000000);
  lc.setRow(0, 1, B01000000);
  lc.setRow(0, 2, B01000000);
  lc.setRow(0, 3, B00000000);
  lc.setRow(0, 4, B00000000);
  lc.setRow(0, 5, B00000000);
  delay(50);
  lc.setRow(0, 0, B01000000);
  lc.setRow(0, 1, B01000000);
  lc.setRow(0, 2, B01000000);
  lc.setRow(0, 3, B01000000);
  lc.setRow(0, 4, B00000000);
  lc.setRow(0, 5, B00000000);
  delay(50);
  lc.setRow(0, 0, B01000000);
  lc.setRow(0, 1, B01000000);
  lc.setRow(0, 2, B01000000);
  lc.setRow(0, 3, B01000000);
  lc.setRow(0, 4, B01000000);
  lc.setRow(0, 5, B00000000);
  delay(50);
  lc.setRow(0, 0, B01000000);
  lc.setRow(0, 1, B01000000);
  lc.setRow(0, 2, B01000000);
  lc.setRow(0, 3, B01000000);
  lc.setRow(0, 4, B01000000);
  lc.setRow(0, 5, B01000000);
  delay(50);
  lc.setRow(0, 0, B01000000);
  lc.setRow(0, 1, B01000000);
  lc.setRow(0, 2, B01000000);
  lc.setRow(0, 3, B01000000);
  lc.setRow(0, 4, B01000000);
  lc.setRow(0, 5, B01100000);
  delay(50);
  lc.setRow(0, 0, B01000000);
  lc.setRow(0, 1, B01000000);
  lc.setRow(0, 2, B01000000);
  lc.setRow(0, 3, B01000000);
  lc.setRow(0, 4, B01000000);
  lc.setRow(0, 5, B01110000);
  delay(50);
  lc.setRow(0, 0, B01000000);
  lc.setRow(0, 1, B01000000);
  lc.setRow(0, 2, B01000000);
  lc.setRow(0, 3, B01000000);
  lc.setRow(0, 4, B01000000);
  lc.setRow(0, 5, B01111000);
  delay(50);
  lc.setRow(0, 0, B01000000);
  lc.setRow(0, 1, B01000000);
  lc.setRow(0, 2, B01000000);
  lc.setRow(0, 3, B01000000);
  lc.setRow(0, 4, B01001000);
  lc.setRow(0, 5, B01111000);
  delay(50);
  lc.setRow(0, 0, B01000000);
  lc.setRow(0, 1, B01000000);
  lc.setRow(0, 2, B01000000);
  lc.setRow(0, 3, B01001000);
  lc.setRow(0, 4, B01001000);
  lc.setRow(0, 5, B01111000);
  delay(50);
  lc.setRow(0, 0, B01000000);
  lc.setRow(0, 1, B01000000);
  lc.setRow(0, 2, B01001000);
  lc.setRow(0, 3, B01001000);
  lc.setRow(0, 4, B01001000);
  lc.setRow(0, 5, B01111000);
  delay(50);
  lc.setRow(0, 0, B01000000);
  lc.setRow(0, 1, B01001000);
  lc.setRow(0, 2, B01001000);
  lc.setRow(0, 3, B01001000);
  lc.setRow(0, 4, B01001000);
  lc.setRow(0, 5, B01111000);
  delay(50);
  lc.setRow(0, 0, B01001000);
  lc.setRow(0, 1, B01001000);
  lc.setRow(0, 2, B01001000);
  lc.setRow(0, 3, B01001000);
  lc.setRow(0, 4, B01001000);
  lc.setRow(0, 5, B01111000);
  delay(50);
  lc.setRow(0, 0, B01001100);
  lc.setRow(0, 1, B01001000);
  lc.setRow(0, 2, B01001000);
  lc.setRow(0, 3, B01001000);
  lc.setRow(0, 4, B01001000);
  lc.setRow(0, 5, B01111000);
  delay(50);
  lc.setRow(0, 0, B01001110);
  lc.setRow(0, 1, B01001000);
  lc.setRow(0, 2, B01001000);
  lc.setRow(0, 3, B01001000);
  lc.setRow(0, 4, B01001000);
  lc.setRow(0, 5, B01111000);
  delay(50);
  lc.setRow(0, 0, B00001110);
  lc.setRow(0, 1, B01001000);
  lc.setRow(0, 2, B01001000);
  lc.setRow(0, 3, B01001000);
  lc.setRow(0, 4, B01001000);
  lc.setRow(0, 5, B01111000);
  delay(50);
  lc.setRow(0, 0, B00001110);
  lc.setRow(0, 1, B00001000);
  lc.setRow(0, 2, B01001000);
  lc.setRow(0, 3, B01001000);
  lc.setRow(0, 4, B01001000);
  lc.setRow(0, 5, B01111000);
  delay(50);
  lc.setRow(0, 0, B00001110);
  lc.setRow(0, 1, B00001000);
  lc.setRow(0, 2, B00001000);
  lc.setRow(0, 3, B01001000);
  lc.setRow(0, 4, B01001000);
  lc.setRow(0, 5, B01111000);
  delay(50);
  lc.setRow(0, 0, B00001110);
  lc.setRow(0, 1, B00001000);
  lc.setRow(0, 2, B00001000);
  lc.setRow(0, 3, B00001000);
  lc.setRow(0, 4, B01001000);
  lc.setRow(0, 5, B01111000);
  delay(50);
  lc.setRow(0, 0, B00001110);
  lc.setRow(0, 1, B00001000);
  lc.setRow(0, 2, B00001000);
  lc.setRow(0, 3, B00001000);
  lc.setRow(0, 4, B00001000);
  lc.setRow(0, 5, B01111000);
  delay(50);
  lc.setRow(0, 0, B00001110);
  lc.setRow(0, 1, B00001000);
  lc.setRow(0, 2, B00001000);
  lc.setRow(0, 3, B00001000);
  lc.setRow(0, 4, B00001000);
  lc.setRow(0, 5, B00111000);
  delay(50);
  lc.setRow(0, 0, B00001110);
  lc.setRow(0, 1, B00001000);
  lc.setRow(0, 2, B00001000);
  lc.setRow(0, 3, B00001000);
  lc.setRow(0, 4, B00001000);
  lc.setRow(0, 5, B00011000);
  delay(50);
  lc.setRow(0, 0, B00001110);
  lc.setRow(0, 1, B00001000);
  lc.setRow(0, 2, B00001000);
  lc.setRow(0, 3, B00001000);
  lc.setRow(0, 4, B00001000);
  lc.setRow(0, 5, B00001000);
  delay(50);
  lc.setRow(0, 0, B00001110);
  lc.setRow(0, 1, B00001000);
  lc.setRow(0, 2, B00001000);
  lc.setRow(0, 3, B00001000);
  lc.setRow(0, 4, B00001000);
  lc.setRow(0, 5, B00000000);
  delay(50);
  lc.setRow(0, 0, B00001110);
  lc.setRow(0, 1, B00001000);
  lc.setRow(0, 2, B00001000);
  lc.setRow(0, 3, B00001000);
  lc.setRow(0, 4, B00000000);
  lc.setRow(0, 5, B00000000);
  delay(50);
  lc.setRow(0, 0, B00001110);
  lc.setRow(0, 1, B00001000);
  lc.setRow(0, 2, B00001000);
  lc.setRow(0, 3, B00000000);
  lc.setRow(0, 4, B00000000);
  lc.setRow(0, 5, B00000000);
  delay(50);
  lc.setRow(0, 0, B00001110);
  lc.setRow(0, 1, B00001000);
  lc.setRow(0, 2, B00000000);
  lc.setRow(0, 3, B00000000);
  lc.setRow(0, 4, B00000000);
  lc.setRow(0, 5, B00000000);
  delay(50);
  lc.setRow(0, 0, B00001110);
  lc.setRow(0, 1, B00000000);
  lc.setRow(0, 2, B00000000);
  lc.setRow(0, 3, B00000000);
  lc.setRow(0, 4, B00000000);
  lc.setRow(0, 5, B00000000);
  delay(50);
  lc.setRow(0, 0, B00000110);
  lc.setRow(0, 1, B00000000);
  lc.setRow(0, 2, B00000000);
  lc.setRow(0, 3, B00000000);
  lc.setRow(0, 4, B00000000);
  lc.setRow(0, 5, B00000000);
  delay(50);
  lc.setRow(0, 0, B00000010);
  lc.setRow(0, 1, B00000000);
  lc.setRow(0, 2, B00000000);
  lc.setRow(0, 3, B00000000);
  lc.setRow(0, 4, B00000000);
  lc.setRow(0, 5, B00000000);
  delay(50);
  lc.setRow(0, 0, B00000000);
  lc.setRow(0, 1, B00000000);
  lc.setRow(0, 2, B00000000);
  lc.setRow(0, 3, B00000000);
  lc.setRow(0, 4, B00000000);
  lc.setRow(0, 5, B00000000);
}
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

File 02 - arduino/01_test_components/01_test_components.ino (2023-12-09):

#include "LedControl.h"

//MAX7219 configuration
#define PIN_MAX72_DATA_IN 12
#define PIN_MAX72_CLK 11
#define PIN_MAX72_LOAD 10
#define MAX72_NB_DEVICES 2

LedControl lc = LedControl(PIN_MAX72_DATA_IN,PIN_MAX72_CLK,PIN_MAX72_LOAD,MAX72_NB_DEVICES);

//Yellow led (TAU)
#define PIN_YELLOW_LED 7

//Red led (DELTA)
#define PIN_RED_LED 6

//Green led (ZETA)
#define PIN_GREEN_LED 5

//Red led (Between HH, MM, SS)
#define PIN_RED_COLONS_LED 13

//Global led configuration
#define DEFAULT_INTENSITY_LED 8

//Debug configuration
#define DEFAULT_DELAY_MS 100

void setup() {
    pinMode(PIN_GREEN_LED, OUTPUT);
    pinMode(PIN_RED_LED, OUTPUT);
    pinMode(PIN_YELLOW_LED, OUTPUT);
    pinMode(PIN_RED_COLONS_LED, OUTPUT);

    int devices = lc.getDeviceCount();
    for(int address = 0; address < devices; address++) {
        lc.shutdown(address,false);
        lc.clearDisplay(address);
        lc.setIntensity(address,DEFAULT_INTENSITY_LED);
        lc.setScanLimit(address, 6);
    }
}

void loop() {
    //Blink red colons
    digitalWrite(PIN_RED_COLONS_LED, HIGH);
    delay(DEFAULT_DELAY_MS);
    digitalWrite(PIN_RED_COLONS_LED, LOW);

   //Display digits on 7 segment displays
   for (int i = 0; i <= 9; i++) {
      //7 segment displays HH:MM:SS
      lc.setChar(0,0,i,false);
      lc.setChar(0,1,i,false);
      lc.setChar(0,2,i,false);
      lc.setChar(0,3,i,false);
      lc.setChar(0,4,i,false);
      lc.setChar(0,5,i,false);
      //7 segment displays days
      lc.setChar(1,2,i,false);
      lc.setChar(1,3,i,false);
      lc.setChar(1,4,i,false);    
      delay(DEFAULT_DELAY_MS);
    }
    
    //Blink green led
    digitalWrite(PIN_GREEN_LED, HIGH);
    delay(DEFAULT_DELAY_MS);
    digitalWrite(PIN_GREEN_LED, LOW); 

    //Blink red led
    digitalWrite(PIN_RED_LED, HIGH);
    delay(DEFAULT_DELAY_MS);
    digitalWrite(PIN_RED_LED, LOW); 

    //Blink yellow led
    digitalWrite(PIN_YELLOW_LED, HIGH);
    delay(DEFAULT_DELAY_MS);
    digitalWrite(PIN_YELLOW_LED, LOW); 
    
    //Bar graphs
    //A
    lc.setRow(1,0,B01000000);
    lc.setRow(1,1,B01000000);
    delay(DEFAULT_DELAY_MS);
    //B
    lc.setRow(1,0,B00100000);
    lc.setRow(1,1,B00100000);      
    delay(DEFAULT_DELAY_MS);
    //C
    lc.setRow(1,0,B00010000);
    lc.setRow(1,1,B00010000);
    delay(DEFAULT_DELAY_MS);    
    //D
    lc.setRow(1,0,B00001000);
    lc.setRow(1,1,B00001000);
    delay(DEFAULT_DELAY_MS);
    //E
    lc.setRow(1,0,B00000100);    
    lc.setRow(1,1,B00000100);
    delay(DEFAULT_DELAY_MS);
    //F
    lc.setRow(1,0,B00000010);
    lc.setRow(1,1,B00000010);
    delay(DEFAULT_DELAY_MS);    
    //G
    lc.setRow(1,0,B00000001);
    lc.setRow(1,1,B00000001);
    delay(DEFAULT_DELAY_MS);
    //DP
    lc.setRow(1,0,B10000000);
    lc.setRow(1,1,B10000000);
    delay(DEFAULT_DELAY_MS);
}

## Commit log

2024-12-05 clean schematics folder
2024-12-05 add more timer pictures
2025-01-22 add pcb 3d models and fbx file for online preview
2025-01-22 add 3d model preview + gerber files
2025-01-24 update 3d pcb + laser cut files
    [Laser cut - Bottom overlay.dxf, Laser cut - Top overlay.dxf, v2 - Timer - PCB.f3d]
2025-01-24 laser cuts folder rename
    [Laser cut - Bottom overlay.dxf, Laser cut - Top overlay.dxf]
2025-01-24 laser cut folder rename
    [Laser cut - Bottom overlay.dxf, Laser cut - Top overlay.dxf]
2025-04-23 add stl files
    [Battery Box Insert Support.stl, Battery Box Insert.stl, Battery Box Usb Adapter.stl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]
2025-04-23 add assembly informations
2025-04-23 add tips for buttons
